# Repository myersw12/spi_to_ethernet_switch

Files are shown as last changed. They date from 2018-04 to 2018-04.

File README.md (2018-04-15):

# spi_to_ethernet_switch
Hardware and software for an Ethernet Switch with an MII to SPI adapter on it.

## Description

This project has 2 parts; a Kicad Project containing the schematic and layout for the board, and the software to interact 
with the board.  The idea was to create a compact ethernet switch suitable for use with low power microcontrollers and single 
board computers.  Micrel produces several ethernet switches in the same family with more ports and this design would make a good 
starting point for using those.

## Kicad Project

The main components of this project are the [Micrel KSZ8863MLL](https://www.microchip.com/wwwproducts/en/KSZ8863) 3 Port Ethernet Switch and the Wiznet W3150A+ Ethernet MAC to SPI Adapter.
The KSZ8863MLL provides 3 ethernet interfaces.  The first 2 include the PHYs and are connected to RJ45 connectors with included magnetics.
The other interface is connected via the MII interface to the [W3150A+](http://www.wiznet.io/product-item/w3150a/).  The SPI pins on W3150A+ are broken out on the board so that they
may be attached to a microcontroller or single board computer.  All of the examples in this project use a Raspberry Pi 2.

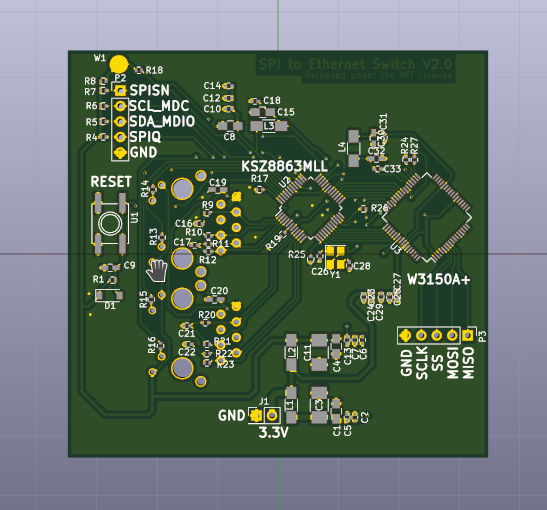
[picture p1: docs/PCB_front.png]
PCB Front

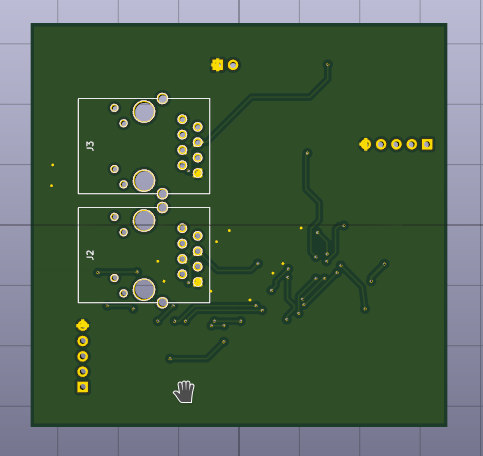
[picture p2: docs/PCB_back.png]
PCB Back


## Software

The software is located in the [code](/code) directory.  This was written for the Raspberry Pi 2 and it is easiest to compile it
on the raspberry pi.  Once it is there, run the makefile in the [src](/code/src) directory.  This creates three executables:
  * tx_example: transmits a raw ethernet frame once a second
  * recv_example: receives raw ethernet frames and prints them as they arrive
  * tap_example: uses the tap interface on the Raspberry Pi to send and receive raw ethernet frames over the SPI interface
  
The W3150A+ offers TCP/IP processing onboard.  Depending on the situation, it might be advantageous to make use of that functionality.
The existing SPI connection will support this.

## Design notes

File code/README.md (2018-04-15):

# Example Usage

The tx_example and recv_example require no setup.  To see them working, connect the board to another networked device.  For the 
tx_example, you will see an ICMP response packet addressed to broadcast.  

## Tap_example setup
The tap_example requires a small amount of setup:
  * Setup Tap Interface: sudo ip tuntap add mode tap
  * Configure Tap Interface: sudo ifconfig tap0 192.168.10.123
  * Ensure that there are no other interfaces active on the same subnet.
  * Run tap_test: ./tap_example tap0 -tap
 
At this point you can send traffic to other devices on the network using the tap interface.

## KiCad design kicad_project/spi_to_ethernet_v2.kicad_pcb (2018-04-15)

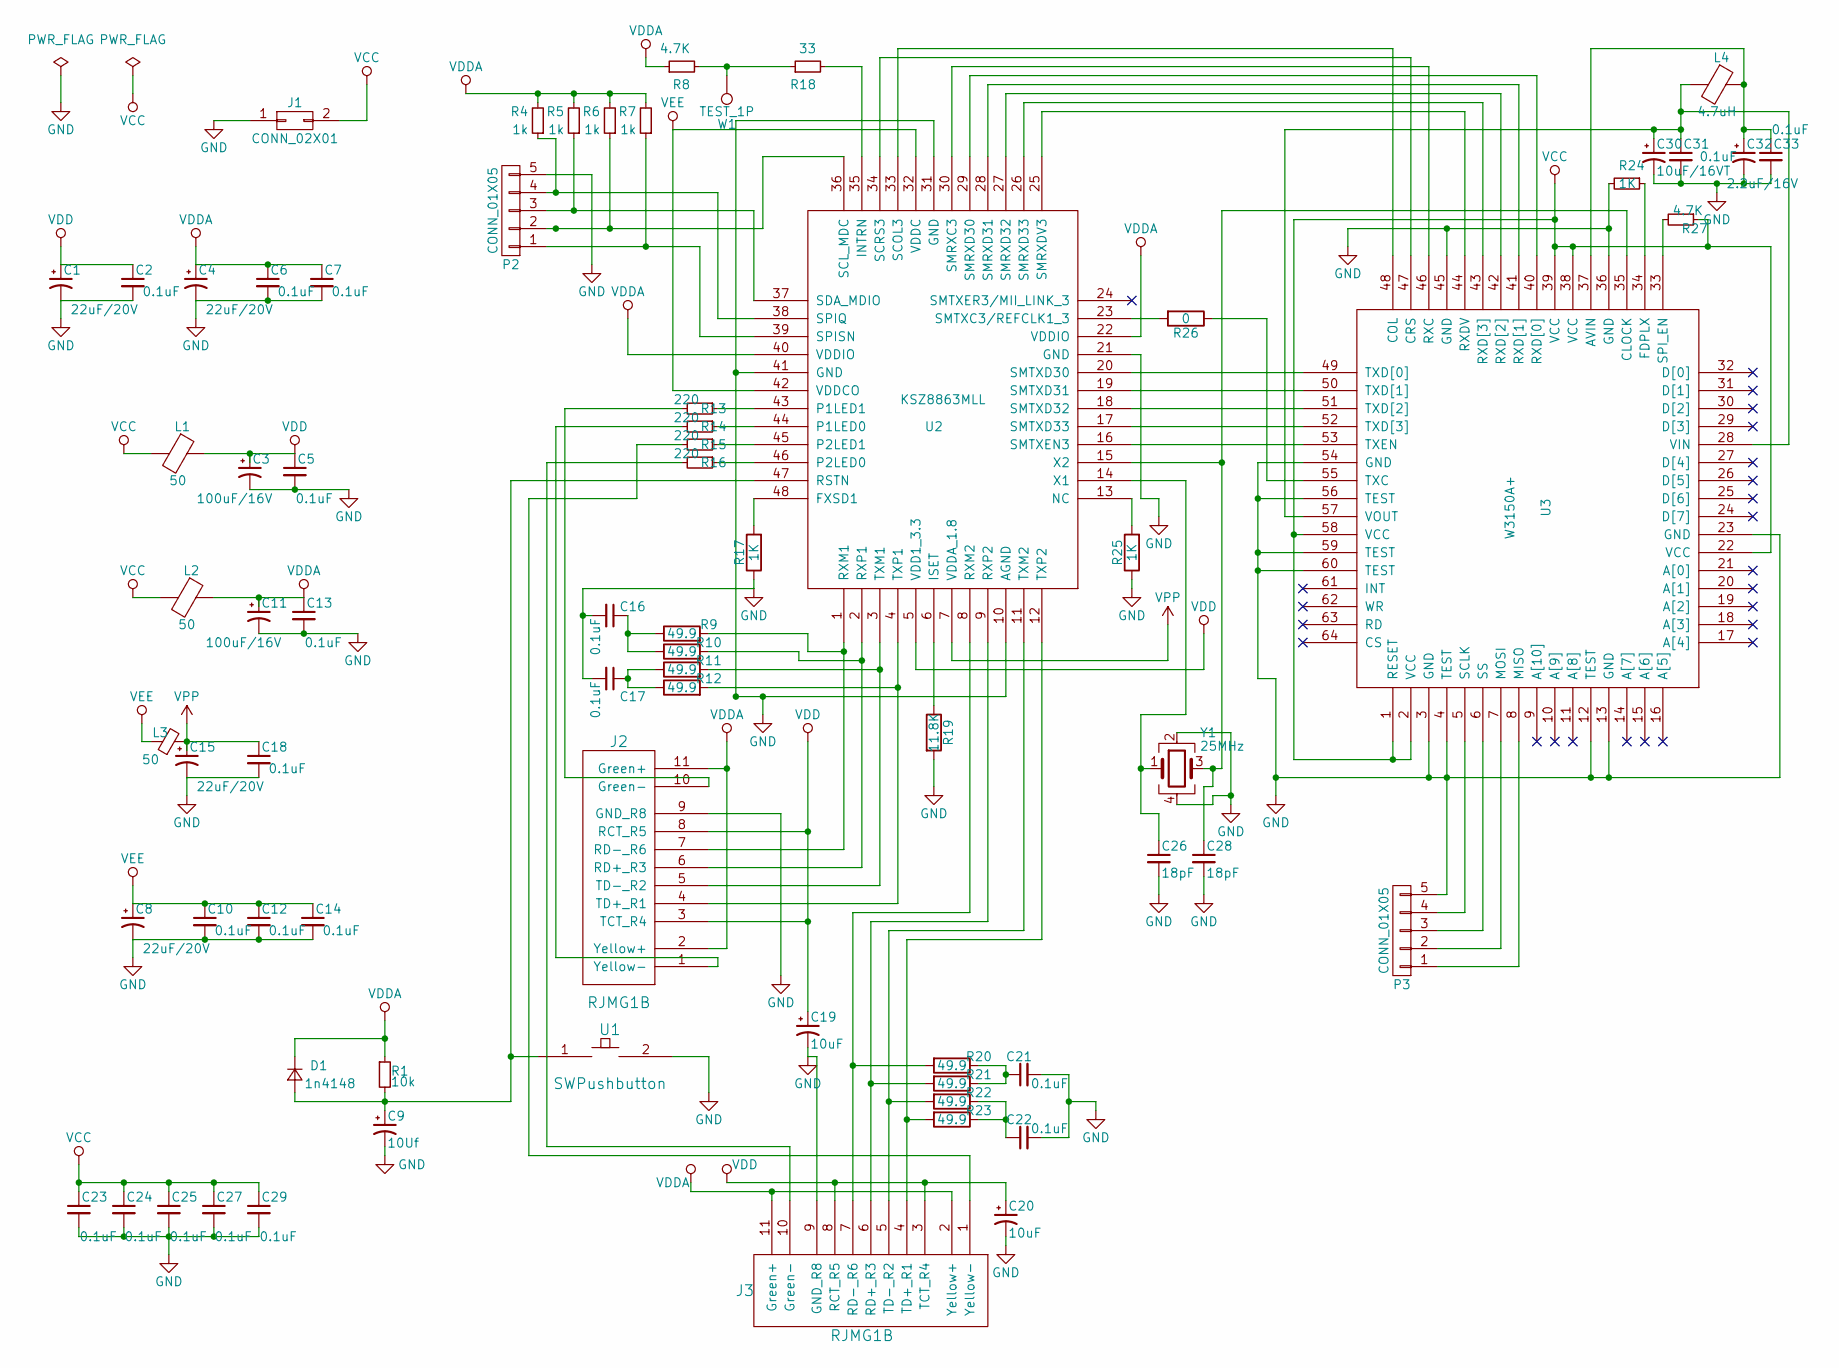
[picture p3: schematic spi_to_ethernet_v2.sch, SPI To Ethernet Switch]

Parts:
C1, C4, C8, C15: 22uF/20V; C_0805_HandSoldering
C2, C5, C6, C7, C10, C12, C13, C14, C16, C17, C18, C21, C22, C23, C24, C25, C27, C29, C31, C33: 0.1uF; C_0402
C3, C11: 100uF/16V; C_1210_HandSoldering
C9: 10Uf; C_0603_HandSoldering
C19, C20: 10uF; C_0603_HandSoldering
C26, C28: 18pF; C_0402
C30: 10uF/16VT; C_0603_HandSoldering
C32: 2.2uF/16V; C_0603_HandSoldering
D1: 1n4148; D_SOD-123
J1: CONN_02X01; Pin_Header_Straight_2x01_Pitch2.54mm
J2, J3: RJMG1B
L1, L2, L3: 50; C_1206_HandSoldering
L4: 4.7uH; C_1206_HandSoldering
P2, P3: CONN_01X05; Pin_Header_Straight_1x05_Pitch2.54mm
R1: 10k; R_0402
R4, R5, R6, R7: 1k; R_0402
R8, R27: 4.7K; R_0402
R9, R10, R11, R12, R20, R21, R22, R23: 49.9; R_0402
R13, R14, R15, R16: 220; R_0402
R17, R24, R25: 1K; R_0402
R18: 33; R_0402
R19: 11.8K; R_0402
R26: 0; R_0402
U1: SWPushbutton; SW_SPST_EVQQ2
U2: KSZ8863MLL; LQFP-48_7x7mm_Pitch0.5mm
U3: W3150A+; LQFP-64_10x10mm_Pitch0.5mm
W1: TEST_1P; Measurement_Point_Round-SMD-Pad_Big
Y1: 25MHz; Crystal_SMD_Abracon_ABM8G-4pin_3.2x2.5mm

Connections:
GND: C1.2, C2.2, C3.2, C4.2, C5.2, C6.2, C7.2, C8.2, C9.2, C10.2, C11.2, C12.2, C13.2, C14.2, C15.2, C16.2, C17.2, C18.2, C19.2, C20.2, C21.2, C22.2, C23.2, C24.2, C25.2, C26.2, C27.2, C28.2, C29.2, C30.2, C31.2, C32.2, C33.2, J1.1, J2.9 (GND_R8), J3.9 (GND_R8), P2.5, P3.5, R17.1, R19.2, R24.2, R25.1, U1.2, U2.10 (AGND), U2.21 (GND), U2.31 (GND), U2.41 (GND), U3.3 (GND), U3.4 (TEST), U3.12 (TEST), U3.13 (GND), U3.23 (GND), U3.36 (GND), U3.45 (GND), U3.54 (GND), U3.56 (TEST), U3.59 (TEST), U3.60 (TEST), Y1.2, Y1.4
unnamed: C9.1, D1.2 (A), R1.2, U1.1, U2.47 (RSTN)
unnamed: C16.1, R9.1, R10.1
unnamed: C17.1, R11.1, R12.1
unnamed: C21.1, R20.1, R21.1
unnamed: C22.1, R22.1, R23.1
unnamed: C26.1, U2.14 (X1), Y1.1
unnamed: C28.1, U2.15 (X2), U3.35 (CLOCK), Y1.3
unnamed: C30.1, C31.1, L4.2, U3.28 (VIN), U3.57 (VOUT)
unnamed: C32.1, C33.1, L4.1, U3.37 (AVIN)
unnamed: J2.1 (Yellow-), R14.2
unnamed: J2.4 (TD+_R1), R12.2, U2.4 (TXP1)
unnamed: J2.5 (TD-_R2), R11.2, U2.3 (TXM1)
unnamed: J2.6 (RD+_R3), R10.2, U2.2 (RXP1)
unnamed: J2.7 (RD-_R6), R9.2, U2.1 (RXM1)
unnamed: J2.10 (Green-), R13.2
unnamed: J3.1 (Yellow-), R15.2
unnamed: J3.4 (TD+_R1), R23.2, U2.12 (TXP2)
unnamed: J3.5 (TD-_R2), R22.2, U2.11 (TXM2)
unnamed: J3.6 (RD+_R3), R21.2, U2.9 (RXP2)
unnamed: J3.7 (RD-_R6), R20.2, U2.8 (RXM2)
unnamed: J3.10 (Green-), R16.2
unnamed: P2.1, R7.1, U2.39 (SPISN)
unnamed: P2.2, R6.1, U2.36 (SCL_MDC)
unnamed: P2.3, R5.1, U2.37 (SDA_MDIO)
unnamed: P2.4, R4.1, U2.38 (SPIQ)
unnamed: P3.1, U3.8 (MISO)
unnamed: P3.2, U3.7 (MOSI)
unnamed: P3.3, U3.6 (SS)
unnamed: P3.4, U3.5 (SCLK)
unnamed: R13.1, U2.43 (P1LED1)
unnamed: R14.1, U2.44 (P1LED0)
unnamed: R15.1, U2.45 (P2LED1)
unnamed: R16.1, U2.46 (P2LED0)
unnamed: R17.2, U2.48 (FXSD1)
unnamed: R8.2, R18.1, W1.1
unnamed: R18.2, U2.35 (INTRN)
unnamed: R19.1, U2.6 (ISET)
unnamed: R24.1, U3.34 (FDPLX)
unnamed: R25.2, U2.13 (NC)
unnamed: R26.1, U3.55 (TXC)
unnamed: R26.2, U2.23 (SMTXC3/REFCLK1_3)
unnamed: R27.2, U3.33 (SPI_EN)
unnamed: U2.16 (SMTXEN3), U3.53 (TXEN)
unnamed: U2.17 (SMTXD33), U3.52 (TXD[3])
unnamed: U2.18 (SMTXD32), U3.51 (TXD[2])
unnamed: U2.19 (SMTXD31), U3.50 (TXD[1])
unnamed: U2.20 (SMTXD30), U3.49 (TXD[0])
unnamed: U2.25 (SMRXDV3), U3.44 (RXDV)
unnamed: U2.26 (SMRXD33), U3.43 (RXD[3])
unnamed: U2.27 (SMRXD32), U3.42 (RXD[2])
unnamed: U2.28 (SMRXD31), U3.41 (RXD[1])
unnamed: U2.29 (SMRXD30), U3.40 (RXD[0])
unnamed: U2.30 (SMRXC3), U3.46 (RXC)
unnamed: U2.33 (SCOL3), U3.48 (COL)
unnamed: U2.34 (SCRS3), U3.47 (CRS)
VCC: C23.1, C24.1, C25.1, C27.1, C29.1, J1.2, L1.2, L2.2, R27.1, U3.1 (RESET), U3.2 (VCC), U3.22 (VCC), U3.38 (VCC), U3.39 (VCC), U3.58 (VCC)
VDD: C1.1, C2.1, C3.1, C5.1, C19.1, C20.1, J2.3 (TCT_R4), J2.8 (RCT_R5), J3.3 (TCT_R4), J3.8 (RCT_R5), L1.1, U2.5 (VDD1_3.3)
VDDA: C4.1, C6.1, C7.1, C11.1, C13.1, D1.1 (K), J2.2 (Yellow+), J2.11 (Green+), J3.2 (Yellow+), J3.11 (Green+), L2.1, R1.1, R4.2, R5.2, R6.2, R7.2, R8.1, U2.22 (VDDIO), U2.40 (VDDIO)
VEE: C8.1, C10.1, C12.1, C14.1, L3.1, U2.32 (VDDC), U2.42 (VDDCO)
VPP: C15.1, C18.1, L3.2, U2.7 (VDDA_1.8)

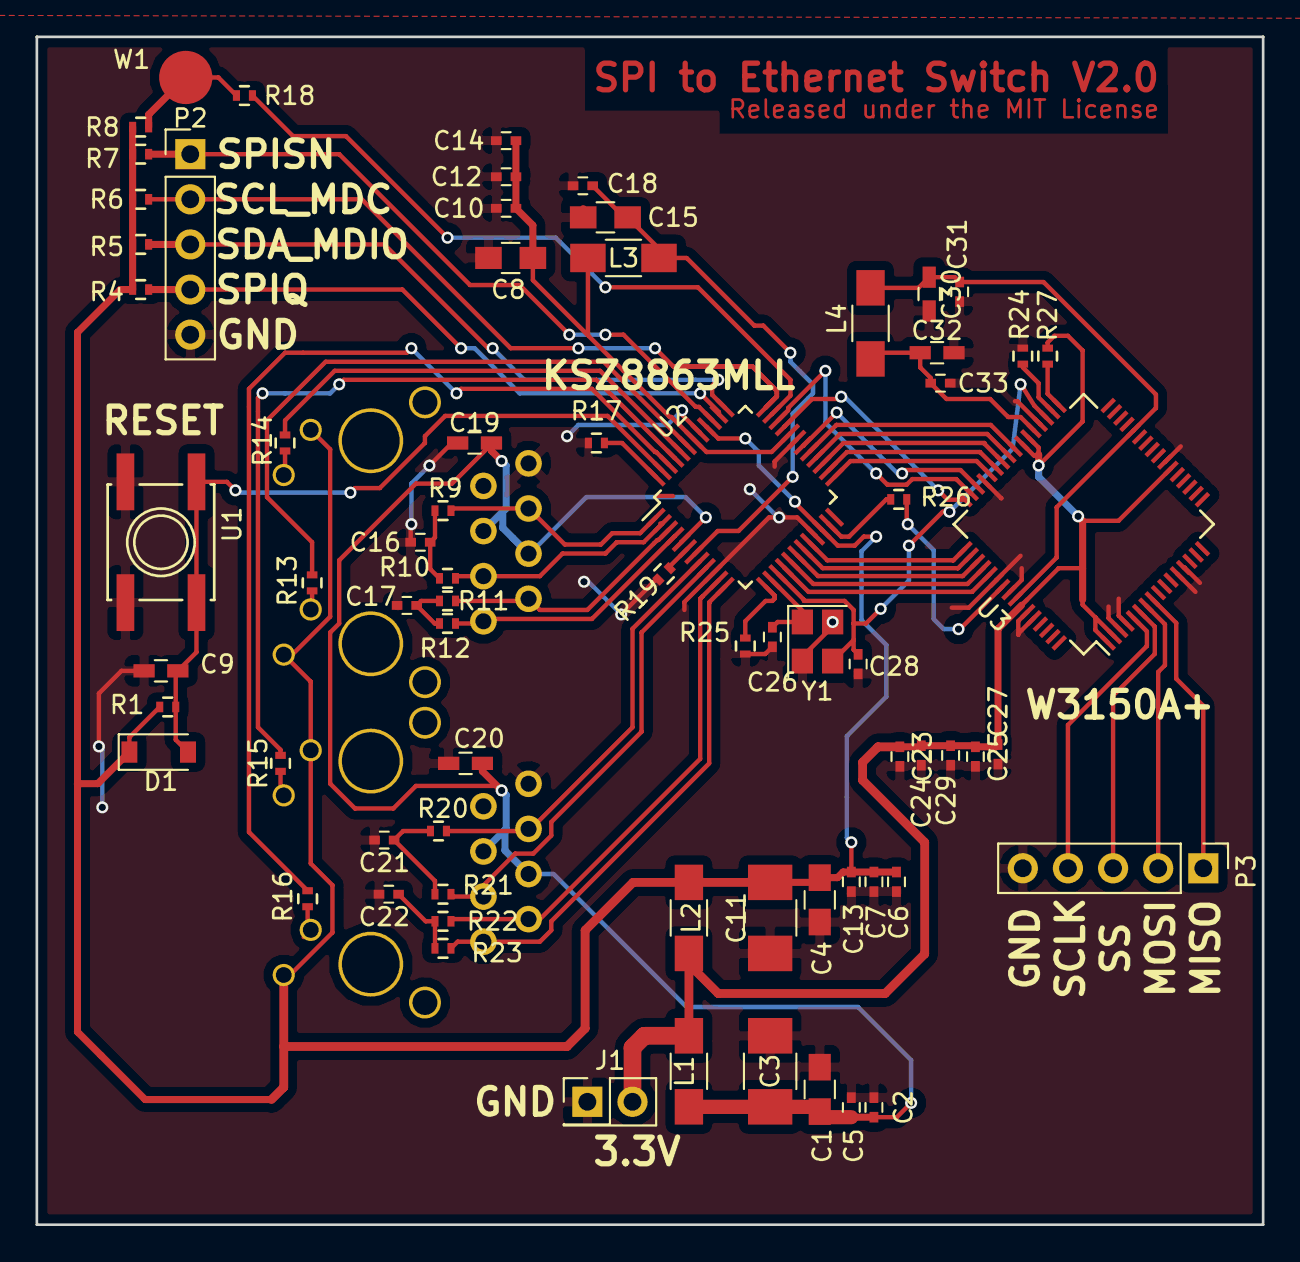
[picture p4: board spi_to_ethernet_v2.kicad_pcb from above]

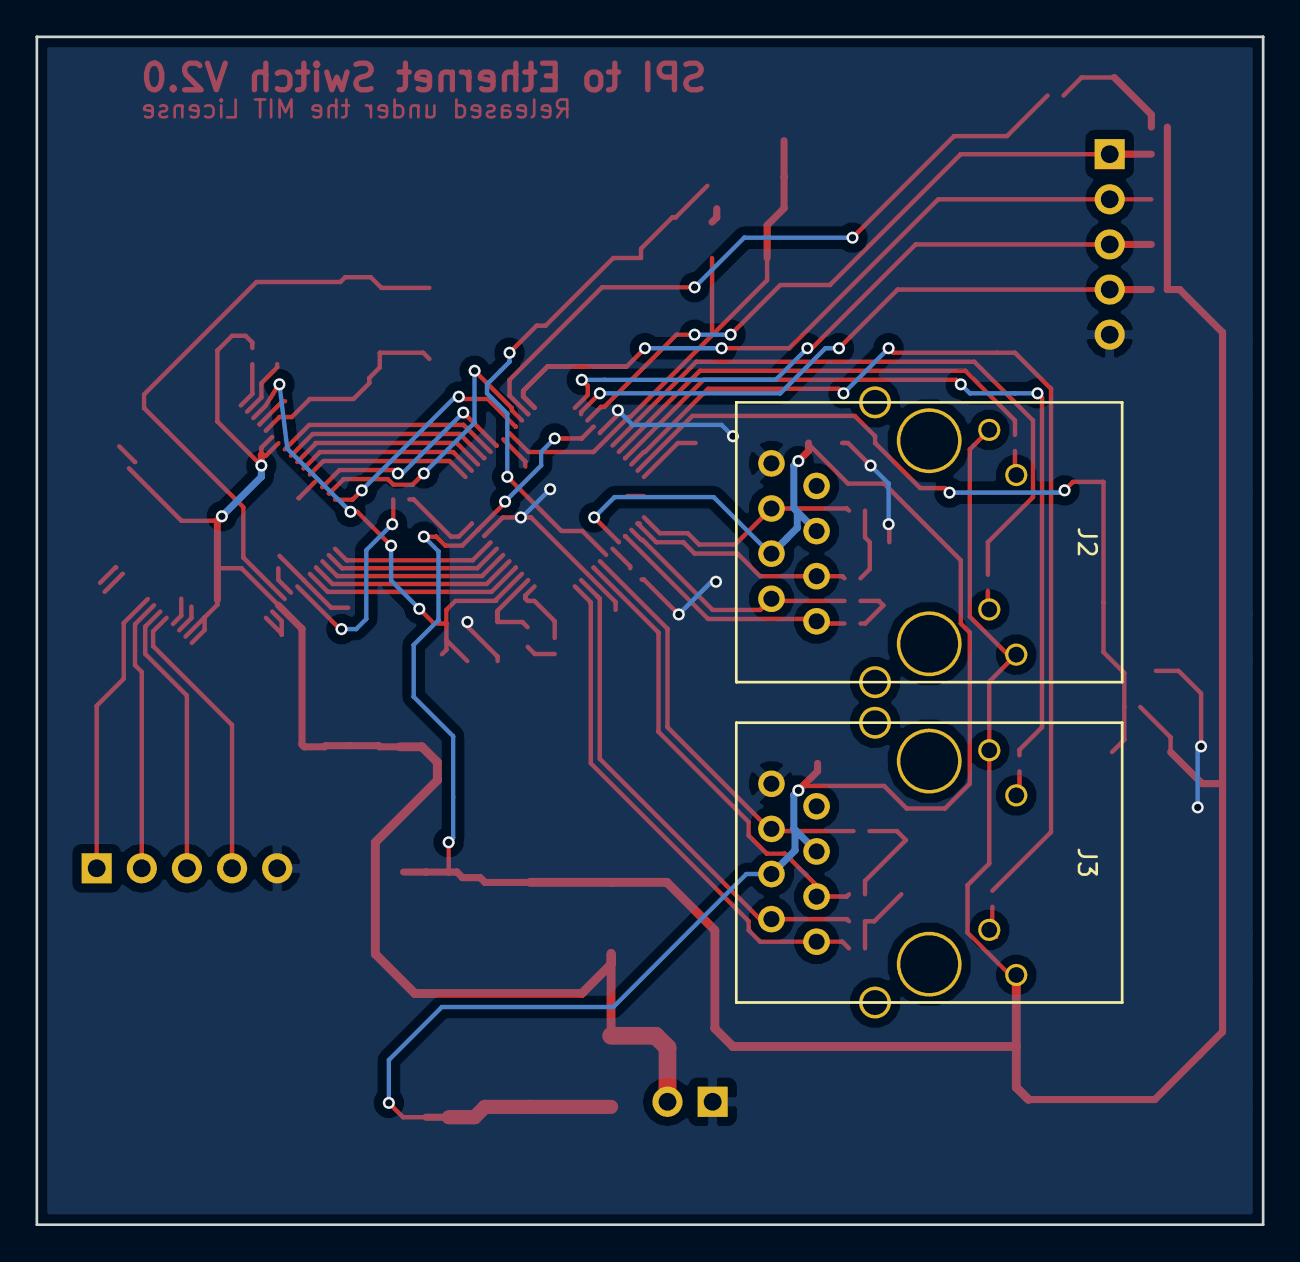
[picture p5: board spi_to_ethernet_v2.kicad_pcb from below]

Board: 2 copper layers, 69.0 x 66.9 mm, 73 parts (2 on the bottom side), 61 nets.

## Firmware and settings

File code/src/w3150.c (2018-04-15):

#include <stdint.h>
#include <w3150.h>
#include <stdio.h>
#include <wiringPiSPI.h>
#include <stdlib.h>
#include <netinet/in.h>
#include <string.h>
#include <unistd.h>


/* This library is designed for use with the 
 * macraw functionality of the W3150+.  Therefore, many
 * of the functions are set up to work with socket 0.
 */

//#define DEBUG_RECV
//#define DEBUG_TX
//#define DEBUG
//#define DEBUG_TRANSFER

static const int CHANNEL = 1;

int initializeSPI(int rate){
    
    int fd = 0;

    printf("Initializing SPI\n");
    fd = wiringPiSPISetupMode(CHANNEL, rate, 0);

    if (fd == -1){
        printf("Error Setting up SPI");
        exit(0);
    }
    else
        return fd;
}

uint8_t spi_transfer(uint8_t* bytes, int len){

    int result = 0;
    
    #ifdef DEBUG_TRANSFER
    int i = 0;
    #endif

    #ifdef DEBUG_TRANSFER
    for (i = 0; i < len; i++)
        printf("%X ", bytes[i]);
    printf("\n");
    #endif

    result = wiringPiSPIDataRW(CHANNEL, (unsigned char*)bytes, len);
    
    #ifdef DEBUG_TRANSFER
    for (i = 0; i < len; i++)
        printf("%X ", bytes[i]);
    printf("\n");
    printf("+++++++++++++++++++++++++\n");
    #endif

    return bytes[len-1];

}

/* Private register IO functions */
static uint8_t w3150_read_register(uint16_t addr){
	
    uint8_t data = 0;
    int len = 4;
    uint8_t buffer[len];

    buffer[0] = W3150_READ;
    buffer[1] = (uint8_t)(addr >> 8);
    buffer[2] = (uint8_t)(addr & 0xff);
    buffer[3] = 0x0;

    data = spi_transfer(buffer, len);

    return data;
}

static void w3150_write_register(uint16_t addr, uint8_t data) {
    
    int len = 4;
    uint8_t buffer[len];

    buffer[0] = W3150_WRITE;
    buffer[1] = (uint8_t)(addr >> 8);
    buffer[2] = (uint8_t)(addr & 0xff);
    buffer[3] = data;
    
    data = spi_transfer(buffer, len);
    
}

void w3150_set_mac(const uint8_t *mac){

    int i;
    for(i = 0; i < 6; i++)
        w3150_write_register((SHAR+i), mac[i]);

}

void w3150_set_ip(const uint8_t *ip){

    int i;
    for(i = 0; i < 4; i++)
        w3150_write_register((SIPR+i), ip[i]);

}

void w3150_set_subnet(const uint8_t *subnet){

    int i;
    for(i = 0; i < 4; i++)
        w3150_write_register((SUBR+i), subnet[i]);

}

void w3150_set_gateway(const uint8_t *gw){

    int i;
    for(i = 0; i < 4; i++)
        w3150_write_register((GAR+i), gw[i]);

}

void w3150_read_mac(uint8_t *mac){

    int i;
    for (i = 0; i < 6; i++)
        mac[i] = w3150_read_register(SHAR+i);

}

void w3150_read_ip(uint8_t *ip){

    int i;
    for (i = 0; i < 4; i++)
        ip[i] = w3150_read_register(SIPR+i);

}

void w3150_read_subnet(uint8_t *subnet){

    int i;
    for (i = 0; i < 4; i++)
        subnet[i] = w3150_read_register(SUBR+i);

}

void w3150_read_gateway(uint8_t *gw){

    int i;
    for (i = 0; i < 4; i++)
        gw[i] = w3150_read_register(GAR+i);

}

/* Public Read and Write Methods */

void w3150_read(uint16_t addr, uint8_t *buf, uint16_t len){

    int i;
    for (i = 0; i < len; i++)
        buf[i] = w3150_read_register(addr + i);
}


void w3150_write(uint16_t addr, uint8_t *buf, uint16_t len){

    int i;
    for (i = 0; i < len; i++){
        w3150_write_register(addr+i, buf[i]);
        #ifdef DEBUG_TRANSFER
        printf("%X ", buf[i]);
        #endif
    }
    #ifdef DEBUG_TRANSFER
    printf("\n");
    #endif
}

/* General configuration methods */

void w3150_init_networking(uint8_t *mac, uint8_t *ip, uint8_t *gw, uint8_t *subnet) {

    // Use 8000000 for the baud rate
    // seems to be the highest we can get
    // and still be reliable
    initializeSPI(8000000);

    // Software reset
    w3150_write_register(MR,0x80);

    // Wait for reset
    usleep(5000);

    // Set mac address
    w3150_set_mac(mac);

    // Set source IP address
    w3150_set_ip(ip);

    // Set gateway
    w3150_set_gateway(gw);

    // Set subnet mask
    w3150_set_subnet(subnet);

    // Debug Logging 
    #ifdef DEBUG

    uint8_t r_mac[6];
    uint8_t r_ip[4];
    uint8_t r_subnet[4];
    uint8_t r_gw[4];

    w3150_read_mac(r_mac);
    w3150_read_ip(r_ip);
    w3150_read_subnet(r_subnet);
    w3150_read_gateway(r_gw);

    printf("----------------w3150 Init----------------\n");
    printf("IP Address  : %d.%d.%d.%d\n",r_ip[0], r_ip[1], r_ip[2], r_ip[3]);
    printf("Subnet Mask : %d.%d.%d.%d\n",r_subnet[0], r_subnet[1], r_subnet[2], r_subnet[3]);
    printf("Gateway     : %d.%d.%d.%d\n",r_gw[0], r_gw[1], r_gw[2], r_gw[3]);
    printf("Mac Address : %x:%x:%x:%x:%x:%x\n",r_mac[0], r_mac[1], r_mac[2], r_mac[3], r_mac[4], r_mac[5]);
    printf("------------------------------------------\n");
    #endif

}

void w3150_ping_block(){
    w3150_write_register(MR, 0x10);
}

void w3150_macraw_open_socket(){
    w3150_write_register(S0_CR, SOCK_OPEN);
}

void w3150_macraw_close_socket(){
    w3150_write_register(S0_CR, SOCK_CLOSE);
}

/* Initialize macraw mode on socket 0
 * When using macraw mode, socket 0 is the only
 * socket that can be used.  Therefore the memory
 * assigned to it is maxed out.
 *
 * Return 1 if successful */
uint8_t w3150_init_macraw() {

    // Set RX Memory Size Register
    // Assigning 8KB to Socket 0
    w3150_write_register(RMSR, 0xFF);

    // Set the TX Memory Size Register
    // Assigning 8KB to Socket 0
    w3150_write_register(TMSR, 0xFF);
   
    // Set mode to macraw and open socket
    // Only Socket 0 supports macraw
    w3150_write_register(S0_MR, MACRAW);
    w3150_macraw_open_socket();

    // check if it actually went to macraw mode
    if (w3150_read_register(S0_SR) != STATUS_MACRAW){
        w3150_macraw_close_socket();
        return 0;
    }
    else
        return 1;
}


uint16_t w3150_macraw_get_received_size_register(){

    uint16_t size = 0;

    size = (w3150_read_register(S0_RX_RSR0) << 8) | w3150_read_register(S0_RX_RSR1);

    return size;
}

uint16_t w3150_macraw_get_tx_free_size(){

    uint16_t size = 0;

    size = (w3150_read_register(S0_TX_FSR0) << 8) | w3150_read_register(S0_TX_FSR1);

    return size;
}

uint16_t w3150_macraw_get_tx_write_pointer(){

    uint16_t pointer = 0;

    pointer = (w3150_read_register(S0_TX_WR0) << 8) | w3150_read_register(S0_TX_WR1);

    return pointer;
}

uint16_t w3150_macraw_get_tx_read_pointer(){

    uint16_t pointer = 0;

    pointer = (w3150_read_register(S0_TX_RD0) << 8) | w3150_read_register(S0_TX_RD1);

    return pointer;
}


uint16_t w3150_macraw_get_read_pointer(){
    
    uint16_t pointer = 0x0000;

    pointer = (w3150_read_register(S0_RX_RD0) << 8) | w3150_read_register(S0_RX_RD1);

    return pointer;
}

uint16_t w3150_macraw_get_rx_write_pointer(){

    uint16_t pointer = 0x0000;

    pointer = (w3150_read_register(S0_RX_WR0) << 8) | w3150_read_register(S0_RX_WR1);

    return pointer;
}

void w3150_macraw_set_recv(){
    // Set RECV command
    w3150_write_register(S0_CR, SOCK_RECV);
}
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

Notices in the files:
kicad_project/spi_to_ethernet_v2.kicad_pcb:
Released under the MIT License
